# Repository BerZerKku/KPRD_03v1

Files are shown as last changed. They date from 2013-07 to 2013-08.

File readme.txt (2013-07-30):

КПРД v3.1

Клеммник комманд передатчика 16-и командный.
В отличии от предыдущих убрана возможность выбора напряжения работы.
Заменены оптроны на более защищенные.
Изменена цепь проверки, для работы с односторонним оптроном.
Входные сопротивления посажены на полигоны, с целью предотвратить их 
выпадания при нагреве.

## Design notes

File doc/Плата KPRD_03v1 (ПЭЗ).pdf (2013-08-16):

Поз.

### обозначе ние

Наименоенвие | Кол. | Примечание
Изм | Лист | № докум. | Подп. | Дата
Разраб. | Щеблыкин М.В | | 16-08-13 | Плата КПРД 03v1 Перечень элементов | Лит. | Лист | Листов
Провер. | Вершинин А.С. | | | | | 1 | 11

ООО
«Прософт-Системы»
Н.контр. | Назаренко А.Н
Утв. | Чирков А.Г.
AV1..AV16 | Оптрон ACPL-M50L-xxxx AVAGO | 16 | хх – любые символы
| (FODM453R2(V) FAIRCHILD, PS8101-AX(xx) CEL)

Конденсаторы

C1 | Чип 1206 X7R 100В 0.1мкФ ±10% | 1
C2 | Чип 1206 Y5V 50В 1мкФ ±20% | 1
C3 | Чип 1210 X7R(X5R, X7S) 50В 10мкФ ±10%(20) | 1
C4 | Чип 0805 X7R 50В 0.1мкФ ±10% | 1
C5 | Чип 1206 X7R 100В 0.1мкФ ±10% | 1
C6 | Чип 0805 X7R 50В 2200пФ ±10% | 1
C7 | Чип 0805 X7R 50В 0.1мкФ ±10% | 1
C8 | Чип 1206 X7R 100В 0.1мкФ ±10% | 1
C9 | Чип 0805 X7R 50В 2200пФ ±10% | 1
C10 | Чип 0805 X7R 50В 0.1мкФ ±10% | 1
C11 | Чип 1206 X7R 100В 0.1мкФ ±10% | 1
C12 | Чип 0805 X7R 50В 2200пФ ±10% | 1
C13 | Чип 0805 X7R 50В 0.1мкФ ±10% | 1
C14 | Чип 1206 X7R 100В 0.1мкФ ±10% | 1
C15 | Чип 0805 X7R 50В 2200пФ ±10% | 1
C16 | Чип 0805 X7R 50В 0.1мкФ ±10% | 1
C17 | Чип 1206 X7R 100В 0.1мкФ ±10% | 1
C18 | Чип 0805 X7R 50В 2200пФ ±10% | 1
C19 | Чип 0805 X7R 50В 0.1мкФ ±10% | 1
C20 | Чип 1206 X7R 100В 0.1мкФ ±10% | 1
C21 | Чип 0805 X7R 50В 2200пФ ±10% | 1
| | | ПБКМ.42 6439.004 ПЭ3

## ПБКМ.42 6439.005 ПЭ3

Лист

2 Изм | Лист | № докум. | Подп. | Дата
C22 | Чип 0805 X7R 50В 0.1мкФ ±10% | 1
C23 | Чип 1206 X7R 100В 0.1мкФ ±10% | 1
C24 | Чип 0805 X7R 50В 2200пФ ±10% | 1
C25 | Чип 0805 X7R 50В 0.1мкФ ±10% | 1
C26 | Чип 1206 X7R 100В 0.1мкФ ±10% | 1
C27 | Чип 0805 X7R 50В 2200пФ ±10% | 1
C28 | Чип 0805 X7R 50В 0.1мкФ ±10% | 1
C29 | Чип 1206 X7R 100В 0.1мкФ ±10% | 1
C30 | Чип 0805 X7R 50В 2200пФ ±10% | 1
C31 | Чип 0805 X7R 50В 0.1мкФ ±10% | 1
C32 | Чип 1206 X7R 100В 0.1мкФ ±10% | 1
C33 | Чип 0805 X7R 50В 2200пФ ±10% | 1
C34 | Чип 0805 X7R 50В 0.1мкФ ±10% | 1
C35 | Чип 1206 X7R 100В 0.1мкФ ±10% | 1
C36 | Чип 0805 X7R 50В 2200пФ ±10% | 1
C37 | Чип 0805 X7R 50В 0.1мкФ ±10% | 1
C38 | Чип 1206 X7R 100В 0.1мкФ ±10% | 1
C39 | Чип 0805 X7R 50В 2200пФ ±10% | 1
C40 | Чип 0805 X7R 50В 0.1мкФ ±10% | 1
C41 | Чип 1206 X7R 100В 0.1мкФ ±10% | 1
C42 | Чип 0805 X7R 50В 2200пФ ±10% | 1
C43 | Чип 0805 X7R 50В 0.1мкФ ±10% | 1
C44 | Чип 1206 X7R 100В 0.1мкФ ±10% | 1
C45 | Чип 0805 X7R 50В 2200пФ ±10% | 1
C46 | Чип 0805 X7R 50В 0.1мкФ ±10% | 1
C47 | Чип 1206 X7R 100В 0.1мкФ ±10% | 1
C48 | Чип 0805 X7R 50В 2200пФ ±10% | 1
C49 | Чип 0805 X7R 50В 0.1мкФ ±10% | 1
C50 | Чип 1206 X7R 100В 0.1мкФ ±10% | 1
C51 | Чип 0805 X7R 50В 2200пФ ±10% | 1

Лист | № докум. | Подп. | Дата

Резисторы

R1..R3 | Чип 2010 1кОм ±5% | 3
R4 | Чип 1206 2кОм ±5% | 1
R5 | SQM500JB-5K1 5.1кОм 5Вт ±5% YAGEO | 1
R6 | Чип 2010 1кОм ±5% | 1
R7 | Чип 1206 2кОм ±5% | 1
R8 | Чип 2010 1.2кОм ±5% | 1
R9 | Чип 2010 100Ом ±5% | 1
R10,R11 | SQM500JB-5K1 5.1кОм 5Вт ±5% YAGEO | 2
R12 | Чип 2010 1кОм ±5% | 1
R13 | Чип 1206 2кОм ±5% | 1
R14 | Чип 2010 1.2кОм ±5% | 1
R15 | Чип 2010 100Ом ±5% | 1
R16,R17 | SQM500JB-5K1 5.1кОм 5Вт ±5% YAGEO | 2
R18 | Чип 1206 2кОм ±5% | 1
R19 | Чип 2010 1кОм ±5% | 1
R20 | Чип 2010 1.2кОм ±5% | 1
R21 | Чип 2010 100Ом ±5% | 1
R22,R23 | SQM500JB-5K1 5.1кОм 5Вт ±5% YAGEO | 2
R24 | Чип 1206 2кОм ±5% | 1
R25 | Чип 2010 1кОм ±5% | 1
R26 | Чип 2010 1.2кОм ±5% | 1
R27 | Чип 2010 100Ом ±5% | 1
R28,R29 | SQM500JB-5K1 5.1кОм 5Вт ±5% YAGEO | 2
R30 | Чип 1206 2кОм ±5% | 1
R31 | Чип 2010 1кОм ±5% | 1
R32 | Чип 2010 1.2кОм ±5% | 1
R33 | Чип 2010 100Ом ±5% | 1
R34,R35 | SQM500JB-5K1 5.1кОм 5Вт ±5% YAGEO | 2
R36 | Чип 1206 2кОм ±5% | 1
R37 | Чип 2010 1кОм ±5% | 1
| | | 3 Изм

Лист | № докум. | Подп. | Дата
R38 | Чип 2010 1.2кОм ±5% | 1
R39 | Чип 2010 100Ом ±5% | 1
R40,R41 | SQM500JB-5K1 5.1кОм 5Вт ±5% YAGEO | 2
R42 | Чип 1206 2кОм ±5% | 1
R43 | Чип 2010 1кОм ±5% | 1
R44 | Чип 2010 1.2кОм ±5% | 1
R45 | Чип 2010 100Ом ±5% | 1
R46,R47 | SQM500JB-5K1 5.1кОм 5Вт ±5% YAGEO | 2
R48 | Чип 1206 2кОм ±5% | 1
R49 | Чип 2010 1кОм ±5% | 1
R50 | Чип 2010 1.2кОм ±5% | 1
R51 | Чип 2010 100Ом ±5% | 1
R52,R53 | SQM500JB-5K1 5.1кОм 5Вт ±5% YAGEO | 2
R54 | Чип 1206 2кОм ±5% | 1
R55 | Чип 2010 1кОм ±5% | 1
R56 | Чип 2010 1.2кОм ±5% | 1
R57 | Чип 2010 100Ом ±5% | 1
R58,R59 | SQM500JB-5K1 5.1кОм 5Вт ±5% YAGEO | 2
R60 | Чип 1206 2кОм ±5% | 1
R61 | Чип 2010 1кОм ±5% | 1
R62 | Чип 2010 1.2кОм ±5% | 1
R63 | Чип 2010 100Ом ±5% | 1
R64,R65 | SQM500JB-5K1 5.1кОм 5Вт ±5% YAGEO | 2
R66 | Чип 1206 2кОм ±5% | 1
R67 | Чип 2010 1кОм ±5% | 1
R68 | Чип 2010 1.2кОм ±5% | 1
R69 | Чип 2010 100Ом ±5% | 1
R70,R71 | SQM500JB-5K1 5.1кОм 5Вт ±5% YAGEO | 2
R72 | Чип 1206 2кОм ±5% | 1
R73 | Чип 2010 1кОм ±5% | 1
R74 | Чип 2010 1.2кОм ±5% | 1
R75 | Чип 2010 100Ом ±5% | 1
| | | 4 Изм

Лист | № докум. | Подп. | Дата
R76,R77 | SQM500JB-5K1 5.1кОм 5Вт ±5% YAGEO | 2
R78 | Чип 1206 2кОм ±5% | 1
R79 | Чип 2010 1кОм ±5% | 1
R80 | Чип 2010 1.2кОм ±5% | 1
R81 | Чип 2010 100Ом ±5% | 1
R82,R83 | SQM500JB-5K1 5.1кОм 5Вт ±5% YAGEO | 2
R84 | Чип 1206 2кОм ±5% | 1
R85 | Чип 2010 1кОм ±5% | 1
R86 | Чип 2010 1.2кОм ±5% | 1
R87 | Чип 2010 100Ом ±5% | 1
R88,R89 | SQM500JB-5K1 5.1кОм 5Вт ±5% YAGEO | 2
R90 | Чип 1206 2кОм ±5% | 1
R91 | Чип 2010 1кОм ±5% | 1
R92 | Чип 2010 1.2кОм ±5% | 1
R93 | Чип 2010 100Ом ±5% | 1
R94,R95 | SQM500JB-5K1 5.1кОм 5Вт ±5% YAGEO | 2
R96 | Чип 1206 2кОм ±5% | 1
R97 | Чип 2010 1кОм ±5% | 1
R98 | Чип 2010 1.2кОм ±5% | 1
R99 | Чип 2010 100Ом ±5% | 1
R100 | SQM500JB-5K1 5.1кОм 5Вт ±5% YAGEO | 1 | Вариант установки ГОСТ 29137-91 200.00.0000.00.00
TV1..TV16 | Трансформатор 78253/55MVC MURATA | 16

Диоды

VD1 | Супрессор P6SMB30СА 30В TSC | 1 | двунаправленный
| (P6SMB30CA LITTLEFUSE, P6SMB30CA VISHAY)
VD2 | BAT54C NXP | 1 | общий коллектор
| (VISHAY, FAIRCHILD и др.)
VD3 | Супрессор P6SMB47СА 47В TSC | 1 | двунаправленный
| (P6SMB47CA LITTLEFUSE, P6SMB47CA VISHAY)
| | | | 5 Изм

Лист | № докум. | Подп. | Дата
VD4 | STPS160A ST | 1
VD5 | Супрессор P6SMB6.8СА 6.8В TSC | 1 | двунаправленный
| (P6SMB6.8CA LITTLEFUSE, P6SMB6.8CA VISHAY)
VD6 | Супрессор P6SMB18А 18В TSC | 1 | однонаправленный
| (P6SMB18A LITTLEFUSE, P6SMB18A VISHAY)
VD7 | Супрессор 1.5SMC300CA 300В LITTLEFUSE | 1 | двунаправленный
| (1.5SMC300CA VISHAY)
VD8 | 1N4148WS FAIRCHILD | 1
| (1N4148WS-V VISHAY)
VD9 | BAT54C NXP | 1 | общий коллектор
| (VISHAY, FAIRCHILD и др.)
VD10 | Супрессор P6SMB6.8СА 6.8В TSC | 1 | двунаправленный
| (P6SMB6.8CA LITTLEFUSE, P6SMB6.8CA VISHAY)
VD11 | Супрессор P6SMB18А 18В TSC | 1 | однонаправленный
| (P6SMB18A LITTLEFUSE, P6SMB18A VISHAY)
VD12 | Супрессор 1.5SMC300CA 300В LITTLEFUSE | 1 | двунаправленный
| (1.5SMC300CA VISHAY)
VD13 | 1N4148WS FAIRCHILD | 1
| (1N4148WS-V VISHAY)
VD14 | BAT54C NXP | 1 | общий коллектор
| (VISHAY, FAIRCHILD и др.)
VD15 | Супрессор P6SMB6.8СА 6.8В TSC | 1 | двунаправленный
| (P6SMB6.8CA LITTLEFUSE, P6SMB6.8CA VISHAY)
VD16 | Супрессор P6SMB18А 18В TSC | 1 | однонаправленный
| (P6SMB18A LITTLEFUSE, P6SMB18A VISHAY)
VD17 | 1N4148WS FAIRCHILD | 1
| (1N4148WS-V VISHAY)
VD18 | Супрессор 1.5SMC300CA 300В LITTLEFUSE | 1 | двунаправленный
| (1.5SMC300CA VISHAY)
VD19 | BAT54C NXP | 1 | общий коллектор
| (VISHAY, FAIRCHILD и др.)
VD20 | Супрессор P6SMB6.8СА 6.8В TSC | 1 | двунаправленный
| | | | 6 Изм

Лист | № докум. | Подп. | Дата
| (P6SMB6.8CA LITTLEFUSE, P6SMB6.8CA VISHAY)
VD21 | Супрессор P6SMB18А 18В TSC | 1 | однонаправленный
| (P6SMB18A LITTLEFUSE, P6SMB18A VISHAY)
VD22 | 1N4148WS FAIRCHILD | 1
| (1N4148WS-V VISHAY)
VD23 | Супрессор 1.5SMC300CA 300В LITTLEFUSE | 1 | двунаправленный
| (1.5SMC300CA VISHAY)
VD24 | BAT54C NXP | 1 | общий коллектор
| (VISHAY, FAIRCHILD и др.)
VD25 | Супрессор P6SMB6.8СА 6.8В TSC | 1 | двунаправленный
| (P6SMB6.8CA LITTLEFUSE, P6SMB6.8CA VISHAY)
VD26 | Супрессор P6SMB18А 18В TSC | 1 | однонаправленный
| (P6SMB18A LITTLEFUSE, P6SMB18A VISHAY)
VD27 | 1N4148WS FAIRCHILD | 1
| (1N4148WS-V VISHAY)
VD28 | Супрессор 1.5SMC300CA 300В LITTLEFUSE | 1 | двунаправленный
| (1.5SMC300CA VISHAY)
VD29 | BAT54C NXP | 1 | общий коллектор
| (VISHAY, FAIRCHILD и др.)
VD30 | Супрессор P6SMB6.8СА 6.8В TSC | 1 | двунаправленный
| (P6SMB6.8CA LITTLEFUSE, P6SMB6.8CA VISHAY)
VD31 | Супрессор P6SMB18А 18В TSC | 1 | однонаправленный
| (P6SMB18A LITTLEFUSE, P6SMB18A VISHAY)
VD32 | 1N4148WS FAIRCHILD | 1
| (1N4148WS-V VISHAY)
VD33 | Супрессор 1.5SMC300CA 300В LITTLEFUSE | 1 | двунаправленный
| (1.5SMC300CA VISHAY)
VD34 | BAT54C NXP | 1 | общий коллектор
| (VISHAY, FAIRCHILD и др.)
VD35 | Супрессор P6SMB6.8СА 6.8В TSC | 1 | двунаправленный
| (P6SMB6.8CA LITTLEFUSE, P6SMB6.8CA VISHAY)
VD36 | Супрессор P6SMB18А 18В TSC | 1 | однонаправленный
| | | | 7 Изм

Лист | № докум. | Подп. | Дата
| (P6SMB18A LITTLEFUSE, P6SMB18A VISHAY)
VD37 | 1N4148WS FAIRCHILD | 1
| (1N4148WS-V VISHAY)
VD38 | Супрессор 1.5SMC300CA 300В LITTLEFUSE | 1 | двунаправленный
| (1.5SMC300CA VISHAY)
VD39 | BAT54C NXP | 1 | общий коллектор
| (VISHAY, FAIRCHILD и др.)
VD40 | Супрессор P6SMB6.8СА 6.8В TSC | 1 | двунаправленный
| (P6SMB6.8CA LITTLEFUSE, P6SMB6.8CA VISHAY)
VD41 | Супрессор P6SMB18А 18В TSC | 1 | однонаправленный
| (P6SMB18A LITTLEFUSE, P6SMB18A VISHAY)
VD42 | 1N4148WS FAIRCHILD | 1
| (1N4148WS-V VISHAY)
VD43 | Супрессор 1.5SMC300CA 300В LITTLEFUSE | 1 | двунаправленный
| (1.5SMC300CA VISHAY)
VD44 | BAT54C NXP | 1 | общий коллектор
| (VISHAY, FAIRCHILD и др.)
VD45 | Супрессор P6SMB6.8СА 6.8В TSC | 1 | двунаправленный
| (P6SMB6.8CA LITTLEFUSE, P6SMB6.8CA VISHAY)
VD46 | Супрессор P6SMB18А 18В TSC | 1 | однонаправленный
| (P6SMB18A LITTLEFUSE, P6SMB18A VISHAY)
VD47 | 1N4148WS FAIRCHILD | 1
| (1N4148WS-V VISHAY)
VD48 | Супрессор 1.5SMC300CA 300В LITTLEFUSE | 1 | двунаправленный
| (1.5SMC300CA VISHAY)
VD49 | BAT54C NXP | 1 | общий коллектор
| (VISHAY, FAIRCHILD и др.)
VD50 | Супрессор P6SMB6.8СА 6.8В TSC | 1 | двунаправленный
| (P6SMB6.8CA LITTLEFUSE, P6SMB6.8CA VISHAY)
VD51 | Супрессор P6SMB18А 18В TSC | 1 | однонаправленный
| (P6SMB18A LITTLEFUSE, P6SMB18A VISHAY)
VD52 | 1N4148WS FAIRCHILD | 1
| | | | 8 Изм

Лист | № докум. | Подп. | Дата
| (1N4148WS-V VISHAY)
VD53 | Супрессор 1.5SMC300CA 300В LITTLEFUSE | 1 | двунаправленный
| (1.5SMC300CA VISHAY)
VD54 | BAT54C NXP | 1 | общий коллектор
| (VISHAY, FAIRCHILD и др.)
VD55 | Супрессор P6SMB6.8СА 6.8В TSC | 1 | двунаправленный
| (P6SMB6.8CA LITTLEFUSE, P6SMB6.8CA VISHAY)
VD56 | Супрессор P6SMB18А 18В TSC | 1 | однонаправленный
| (P6SMB18A LITTLEFUSE, P6SMB18A VISHAY)
VD57 | 1N4148WS FAIRCHILD | 1
| (1N4148WS-V VISHAY)
VD58 | Супрессор 1.5SMC300CA 300В LITTLEFUSE | 1 | двунаправленный
| (1.5SMC300CA VISHAY)
VD59 | BAT54C NXP | 1 | общий коллектор
| (VISHAY, FAIRCHILD и др.)
VD60 | Супрессор P6SMB6.8СА 6.8В TSC | 1 | двунаправленный
| (P6SMB6.8CA LITTLEFUSE, P6SMB6.8CA VISHAY)
VD61 | Супрессор P6SMB18А 18В TSC | 1 | однонаправленный
| (P6SMB18A LITTLEFUSE, P6SMB18A VISHAY)
VD62 | 1N4148WS FAIRCHILD | 1
| (1N4148WS-V VISHAY)
VD63 | Супрессор 1.5SMC300CA 300В LITTLEFUSE | 1 | двунаправленный
| (1.5SMC300CA VISHAY)
VD64 | BAT54C NXP | 1 | общий коллектор
| (VISHAY, FAIRCHILD и др.)
VD65 | Супрессор P6SMB6.8СА 6.8В TSC | 1 | двунаправленный
| (P6SMB6.8CA LITTLEFUSE, P6SMB6.8CA VISHAY)
VD66 | Супрессор P6SMB18А 18В TSC | 1 | однонаправленный
| (P6SMB18A LITTLEFUSE, P6SMB18A VISHAY)
VD67 | 1N4148WS FAIRCHILD | 1
| (1N4148WS-V VISHAY)
VD68 | Супрессор 1.5SMC300CA 300В LITTLEFUSE | 1 | двунаправленный
| | | | 9 Изм

Лист | № докум. | Подп. | Дата
| (1.5SMC300CA VISHAY)
VD69 | BAT54C NXP | 1 | общий коллектор
| (VISHAY, FAIRCHILD и др.)
VD70 | Супрессор P6SMB6.8СА 6.8В TSC | 1 | двунаправленный
| (P6SMB6.8CA LITTLEFUSE, P6SMB6.8CA VISHAY)
VD71 | Супрессор P6SMB18А 18В TSC | 1 | однонаправленный
| (P6SMB18A LITTLEFUSE, P6SMB18A VISHAY)
VD72 | 1N4148WS FAIRCHILD | 1
| (1N4148WS-V VISHAY)
VD73 | Супрессор 1.5SMC300CA 300В LITTLEFUSE | 1 | двунаправленный
| (1.5SMC300CA VISHAY)
VD74 | BAT54C NXP | 1 | общий коллектор
| (VISHAY, FAIRCHILD и др.)
VD75 | Супрессор P6SMB6.8СА 6.8В TSC | 1 | двунаправленный
| (P6SMB6.8CA LITTLEFUSE, P6SMB6.8CA VISHAY)
VD76 | Супрессор P6SMB18А 18В TSC | 1 | однонаправленный
| (P6SMB18A LITTLEFUSE, P6SMB18A VISHAY)
VD77 | 1N4148WS FAIRCHILD | 1
| (1N4148WS-V VISHAY)
VD78 | Супрессор 1.5SMC300CA 300В LITTLEFUSE | 1 | двунаправленный
| (1.5SMC300CA VISHAY)
VD79 | BAT54C NXP | 1 | общий коллектор
| (VISHAY, FAIRCHILD и др.)
VD80 | Супрессор P6SMB6.8СА 6.8В TSC | 1 | двунаправленный
| (P6SMB6.8CA LITTLEFUSE, P6SMB6.8CA VISHAY)
VD81 | Супрессор P6SMB18А 18В TSC | 1 | однонаправленный
| (P6SMB18A LITTLEFUSE, P6SMB18A VISHAY)
VD82 | 1N4148WS FAIRCHILD | 1
| (1N4148WS-V VISHAY)
VD83 | Супрессор 1.5SMC300CA 300В LITTLEFUSE | 1 | двунаправленный
| (1.5SMC300CA VISHAY)
VD84 | BAT54C NXP | 1 | общий коллектор
| | | | 10 Изм

| | | | 11 Изм
Лист | № докум. | Подп. | Дата

(VISHAY, FAIRCHILD и др.)

VT1 | Транзистор BCV72 NXP | 1
| (FAIRCHILD)

Разъемы

X1 | DIN 41612 3*32 96 MR | 1 | вилка угловая
X2 | 231-576/001-000 WAGO | 1 | 16 контактов, угловой
X3 | 231-576/001-000 WAGO | 1 | 16 контактов, угловой
X4 | PLS-2 | 1 | 2.54мм

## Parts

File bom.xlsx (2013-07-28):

Item Number | Description | Case | Quantity | Part Reference | Comment
7 | Диод 1N4148WS FAIRCHILD (1N4148WS-V VISHAY) | SOD-323 | 16 | VD8,VD13,VD17,VD22,VD27,VD32,VD37,VD42,VD47,VD52,VD57,VD62,VD67,VD72,VD77,VD82
9 | Диод BAT54C NXP (VISHAY, FAIRCHILD и др.) | SOT-23_3 | 17 | VD2,VD9,VD14,VD19,VD24,VD29,VD34,VD39,VD44,VD49,VD54,VD59,VD64,VD69,VD74,VD79,VD84 | общий коллектор
11 | Диод STPS160A ST | DO-214AC | 1 | VD4
13 | Супрессор P6SMB6.8СА 6.8В двунаправленный TSC (P6SMB6.8CA LITTLEFUSE, P6SMB6.8CA VISHAY) | DO-214AA | 16 | VD5,VD10,VD15,VD20,VD25,VD30,VD35,VD40,VD45,VD50,VD55,VD60,VD65,VD70,VD75,VD80
15 | Супрессор P6SMB18А 18В однонаправленный TSC (P6SMB18A LITTLEFUSE, P6SMB18A VISHAY) | DO-214AA | 16 | VD6,VD11,VD18,VD23,VD28,VD33,VD38,VD43,VD48,VD53,VD58,VD63,VD68,VD73,VD78,VD83
17 | Супрессор P6SMB30СА 30В двунаправленный TSC (P6SMB30CA LITTLEFUSE, P6SMB30CA VISHAY) | DO-214AA | 1 | VD1
19 | Супрессор P6SMB47СА 47В двунаправленный TSC (P6SMB47CA LITTLEFUSE, P6SMB47CA VISHAY) | DO-214AA | 1 | VD3
21 | Супрессор 1.5SMC300CA 300В двунаправленный LITTLEFUSE (1.5SMC300CA VISHAY) | DO-214AB | 16 | VD7,VD12,VD16,VD21,VD26,VD31,VD36,VD41,VD46,VD51,VD56,VD61,VD66,VD71,VD76,VD81
23
25 | Конденсатор - чип 0805 X7R 50В 2200пФ ±10% | 0805 | 16 | C6,C9,C12,C15,C18,C21,C24,C27,C30,C33,C36,C39,C42,C45,C48,C51
27 | Конденсатор - чип 1206 X7R 100В 0.1мкФ ±10% | 1206 | 17 | C1,C5,C8,C11,C14,C17,C20,C23,C26,C29,C32,C35,C38,C41,C44,C47,C50
29 | Конденсатор - чип 0805 X7R 50В 0.1мкФ ±10% | 0805 | 16 | C4,C7,C10,C13,C16,C19,C22,C25,C28,C31,C34,C37,C40,C43,C46,C49
31 | Конденсатор - чип 1206 Y5V 50В 1мкФ ±20% | 1206 | 1 | C2
33 | Конденсатор - чип 1210 X7R(X5R, X7S) 50В 10мкФ ±10%(20) | 1210 | 1 | C3
35
37 | Оптрон ACPL-M50L-xxxx AVAGO (FODM453R2(V) FAIRCHILD, PS8101-AX(xx) CEL) | SMT_6 | 16 | AV1-AV16
39
41 | Разъем 231-576/001-000 WAGO | 16 pins | 2 | X2,X3 | 16 контактов на плату
43 | Разъем DIN 41612 3*32 96 MR вилка угловая | 96 pins | 1 | X1 | угловой, вилка, ряды А,В и С по 32 контакта
45 | Разъем PLS-2 | 2 pins | 1 | X4 | 2.54мм
47
49 | Резистор - чип 2010 100Ом ±5% | 2010 | 16 | R9,R15,R21,R27,R33,R39,R45,R51,R57,R63,R69,R75,R81,R87,R93,R99
51 | Резистор - чип 2010 1кОм ±5% | 2010 | 18 | R1,R2,R6,R12,R18,R24,R30,R36,R42,R48,R54,R60,R66,R72,R78,R84,R90,R96
53 | Резистор - чип 1206 1кОм ±5% | 1206 | 1 | R3
55 | Резистор - чип 2010 1.2кОм ±5% | 2010 | 16 | R8,R14,R19,R25,R31,R37,R43,R49,R55,R61,R67,R73,R79,R85,R91,R97
57 | Резистор - чип 1206 2кОм ±5% | 1206 | 17 | R4,R7,R13,R20,R26,R32,R38,R44,R50,R56,R62,R68,R74,R80,R86,R92,R98
59 | Резистор SQM500JB-5K1 5.1кОм 5Вт ±5% | 2 pins | 32 | R5,R10,R11,R16,R17,R22,R23,R28,R29,R34,R35,R40,R41,R46,R47,R52,R53,R58,R59,R64,R65,R70,R71,R76,R77,R82,R83,R88,R89,R94,R95,R100 | Вариант установки ГОСТ 29137-91 200.00.0000.00.00
61
63 | Транзистор BCV72 NXP | SOT-23 | 1 | VT1
65
67 | Трансформатор 78253/55MVC MURATA | SM-6 | 16 | TV1-TV16

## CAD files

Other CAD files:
doc/Плата KPRD_03v1 (СБ).dwg

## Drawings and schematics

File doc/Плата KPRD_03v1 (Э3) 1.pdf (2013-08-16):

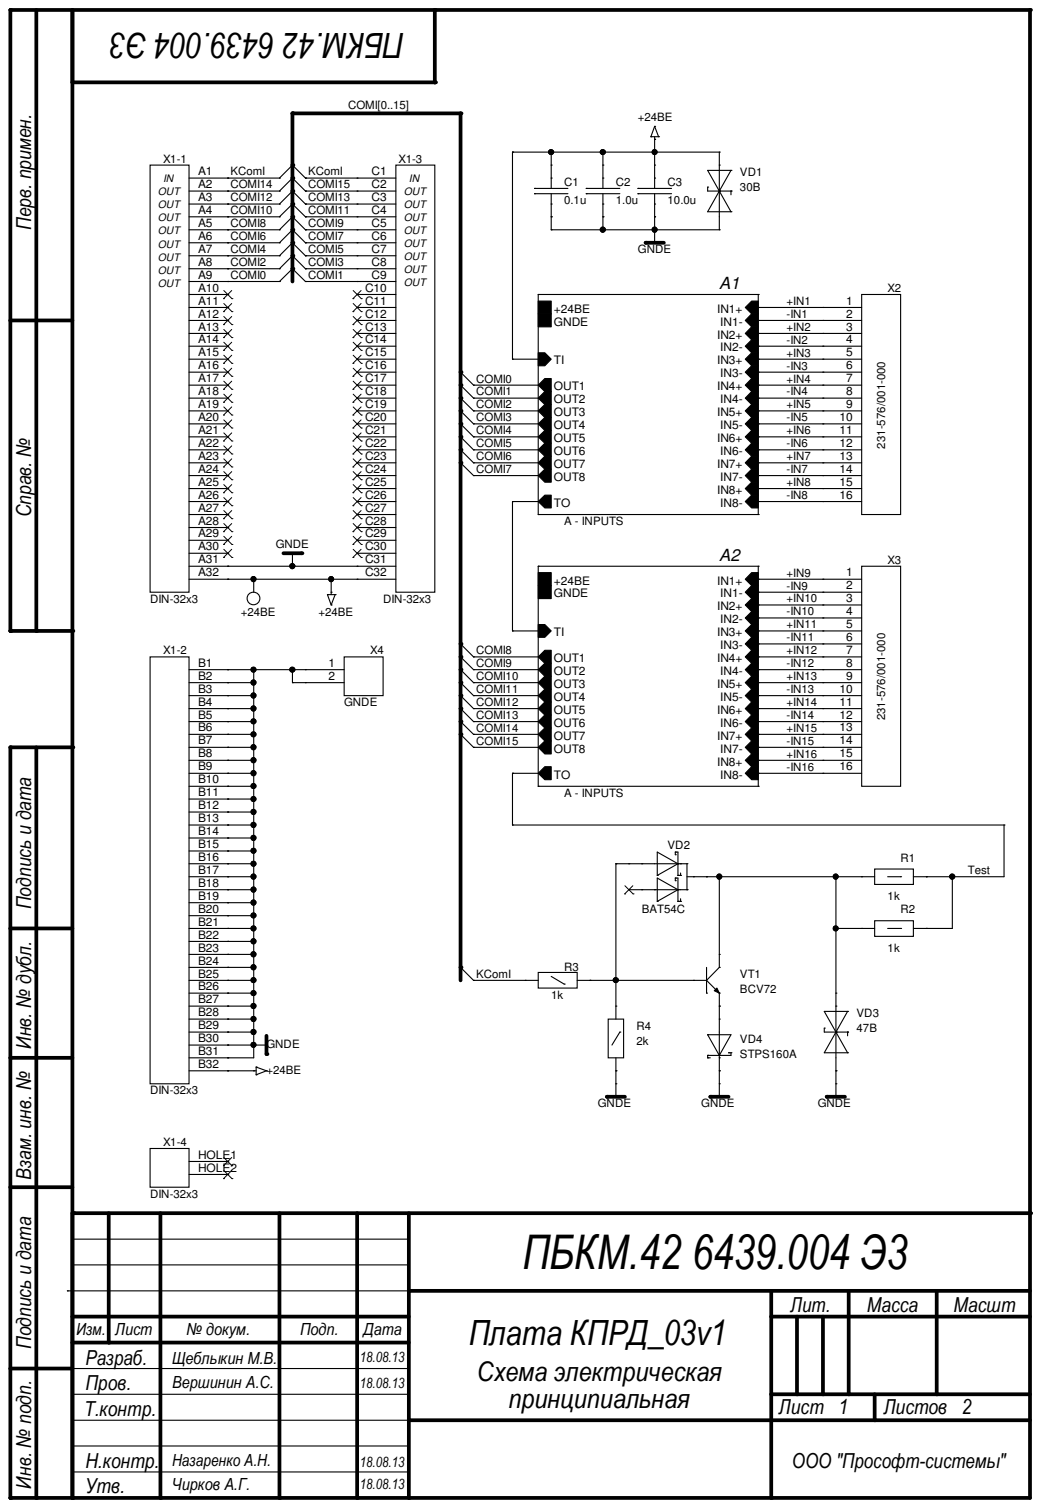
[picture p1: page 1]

Инв. № подп. Подпись и дата Взам. инв. № Инв. № дубл. П

ПБКМ.42 6439.004 Э3

Плата КПРД_03v1 Схема электрическая принципиальная | Лит. | Масса | Масшт

Изм. | Лист | № докум. | Подп. | Дата
Разраб. | | Щеблыкин М.В. | | 18.08.13
Пров. | Вершинин А.С. | | 18.08.13
Т.контр. | | | | | Лист 1 | Листов 2

Н.контр. | Назаренко А.Н. | 18.08.13
Утв. | Чирков А.Г. | 18.08.13

ООО "Прософт-системы"

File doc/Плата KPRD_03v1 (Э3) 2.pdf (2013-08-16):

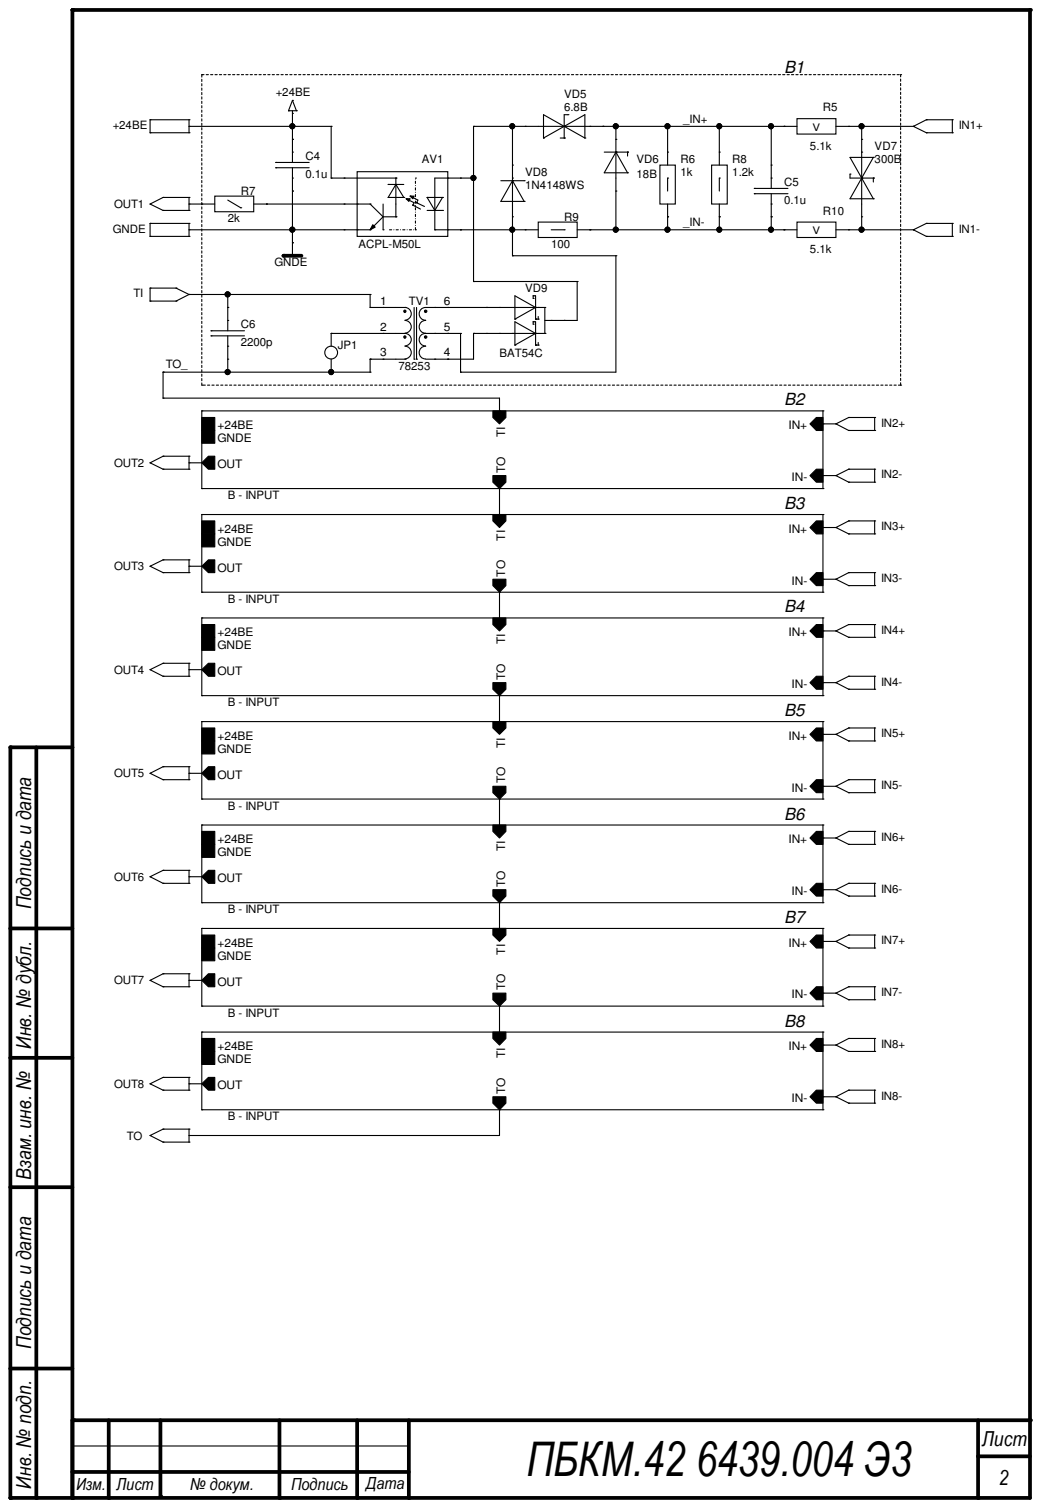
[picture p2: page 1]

Инв. № подп. Подпись и дата Взам. инв. № Инв. № дубл. Подпись и дата

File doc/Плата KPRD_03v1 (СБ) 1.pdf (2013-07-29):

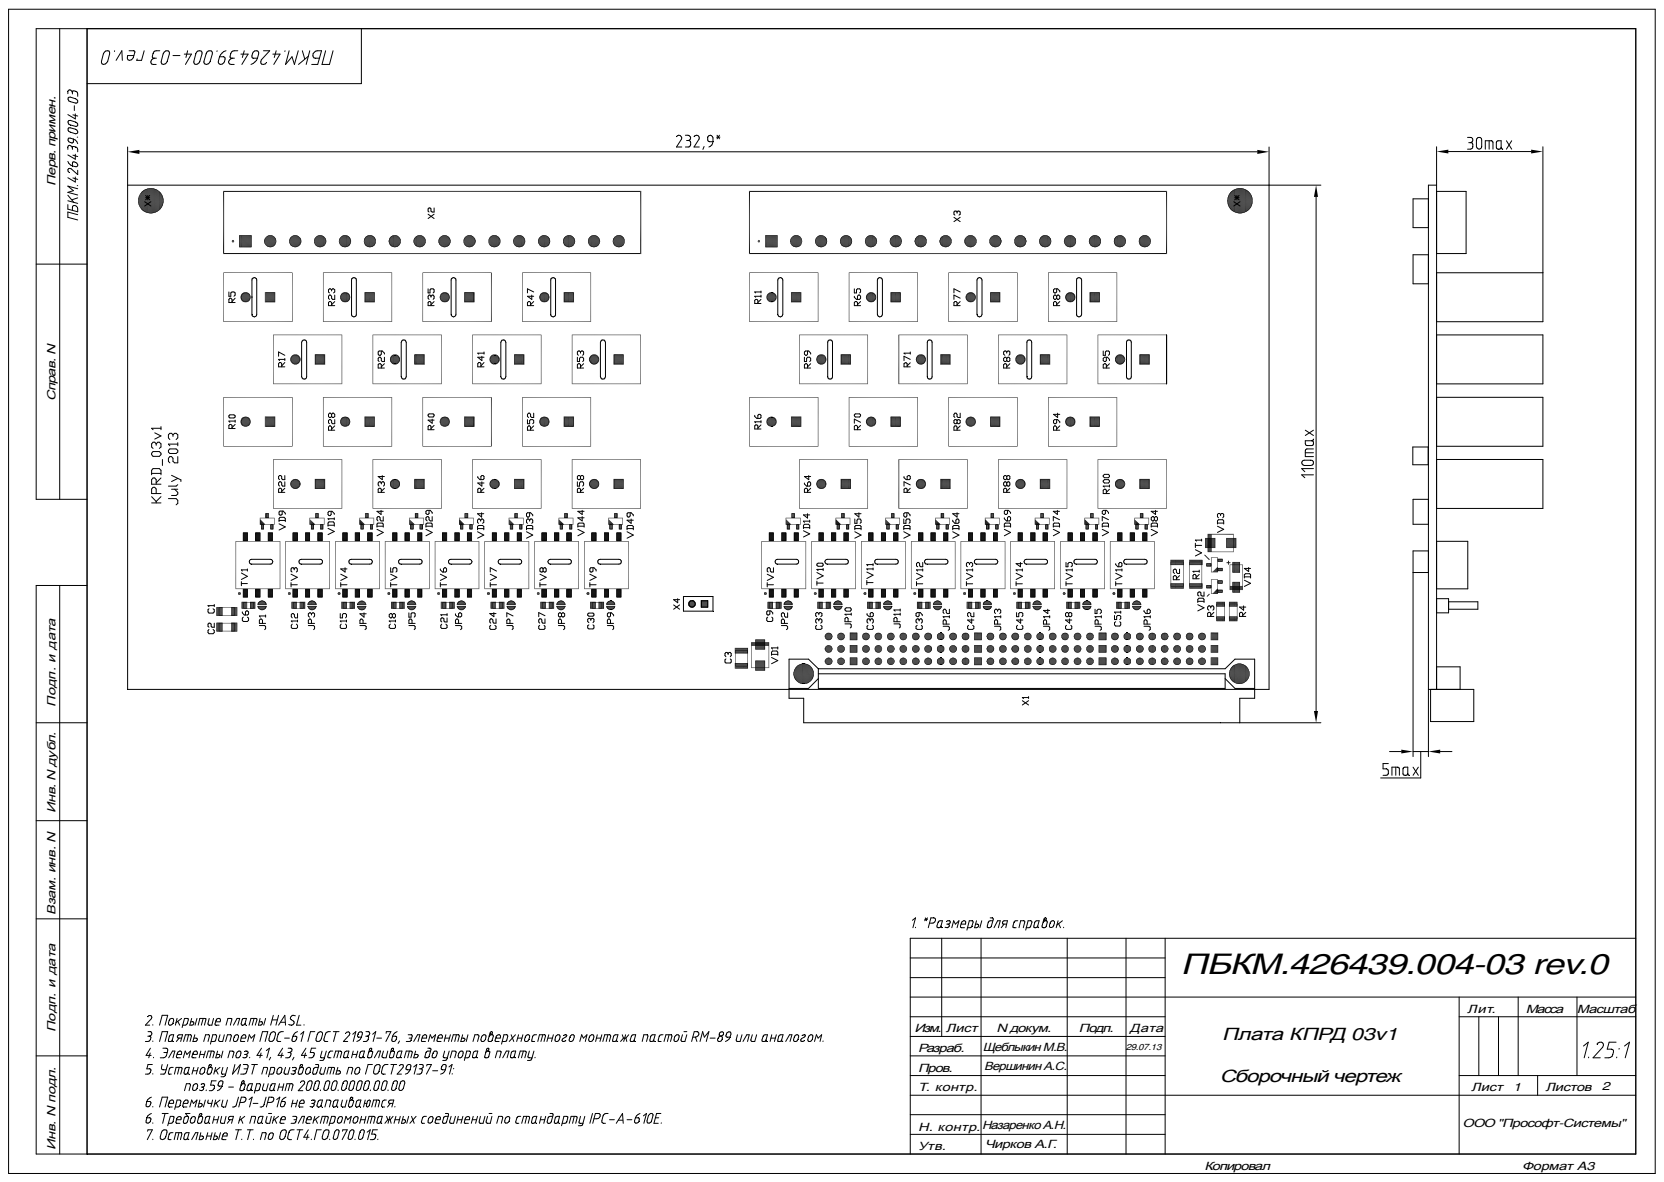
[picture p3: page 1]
Копировал; Формат A3

Перв. примен. Справ. N Подп. и дата Инв. N дубл. Взам. инв. N Подп. и дата Инв. N подл.

ПБКМ.426439.004-03 rev.0

Плата КПРД 03v1 Сборочный чертеж | Лит. | Масса | Масштаб

Изм. Лист | N докум. | Подп. | Дата
Разраб. | Щеблыкин М.В. | | 29.07.13
Пров. | Вершинин А.С.
Т. контр. | | | | Лист 1 | Листов 2

Н. контр. | Назаренко А.Н.
Утв. | Чирков А.Г.

ООО "Прософт-Системы"

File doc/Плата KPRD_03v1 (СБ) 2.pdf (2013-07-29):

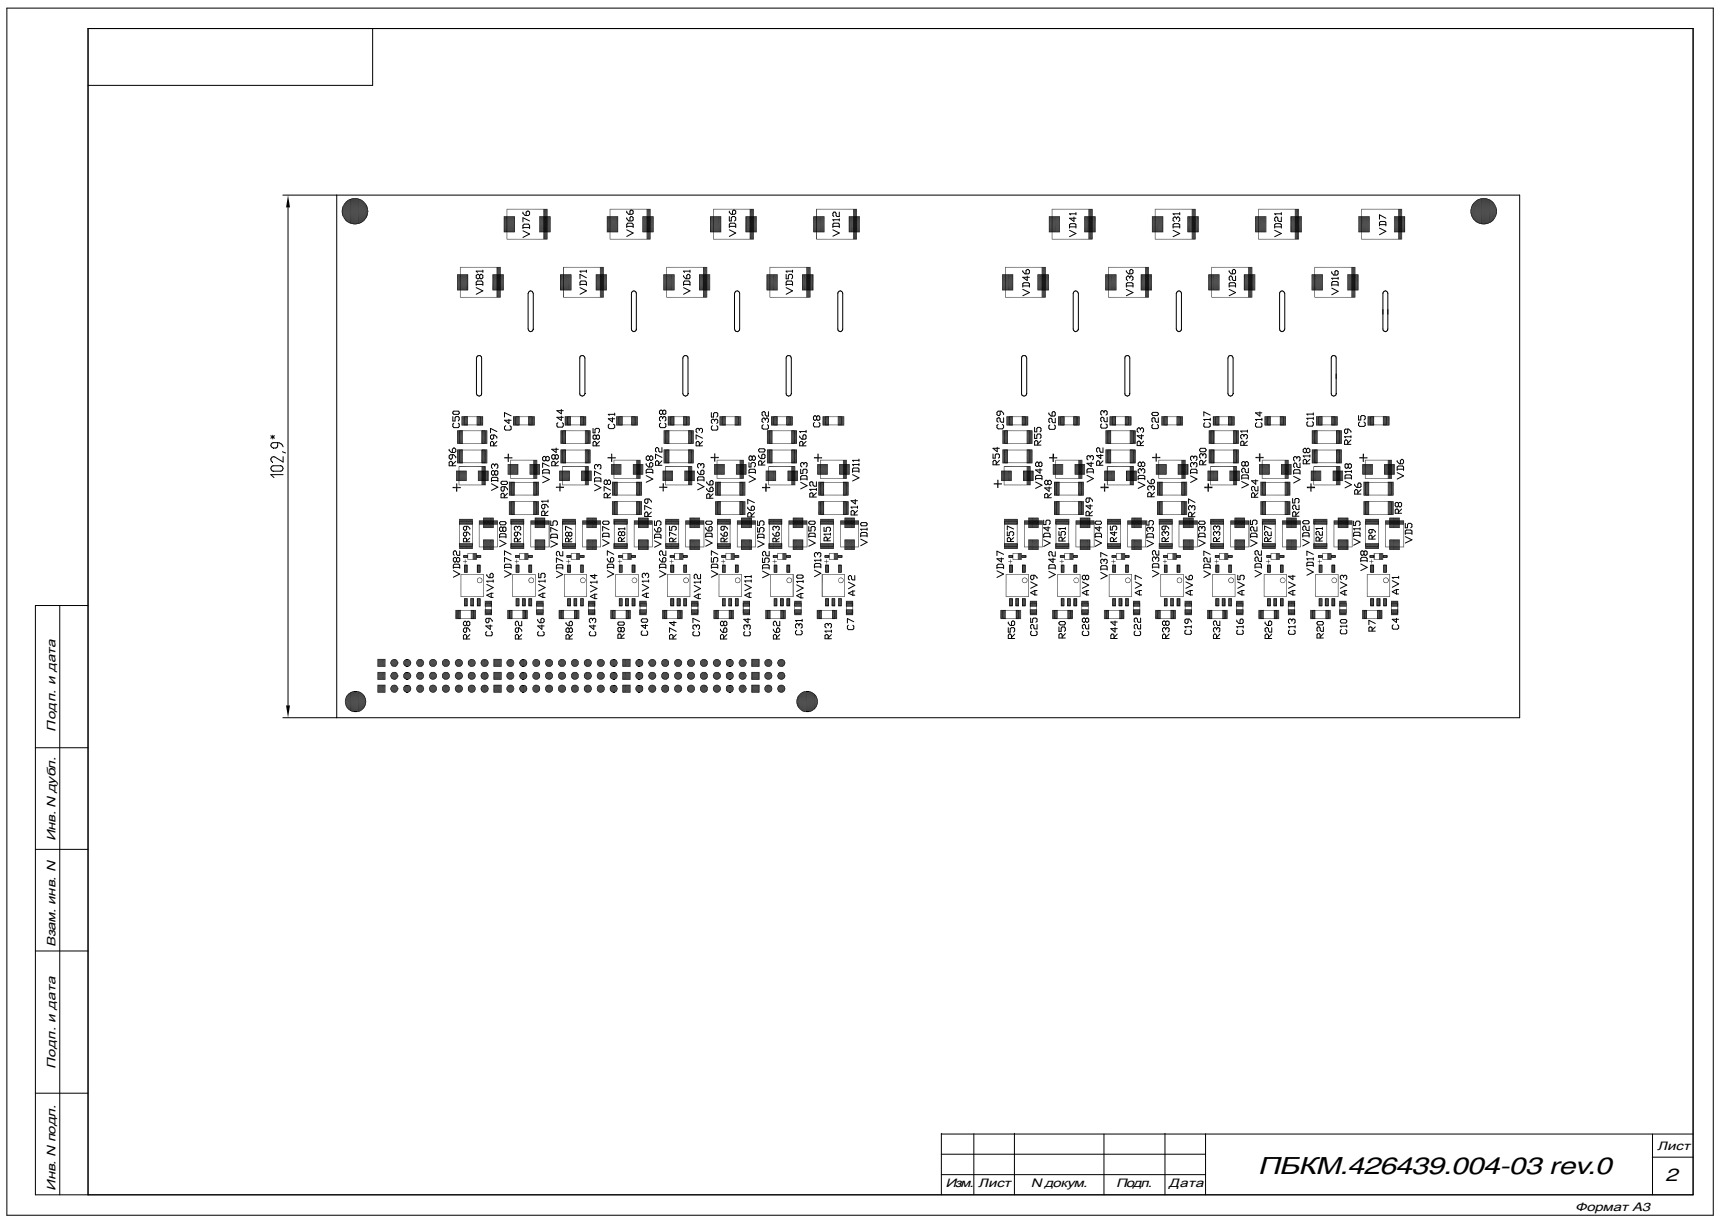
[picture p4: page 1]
Лист; Формат A3; Изм. Лист; N докум.; Подп.; Дата; ПБКМ.426439.004-03 rev.0

Подп. и дата Инв. N дубл. Взам. инв. N Подп. и дата Инв. N подл.

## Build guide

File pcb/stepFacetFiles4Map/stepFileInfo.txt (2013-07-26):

#STEP_FILE ! FILE_SIZE | MOD_TIME

LED 0603 Green.step ! 113239 ! 1372843388
DO-214AB.STEP ! 787405 ! 1372619486
Capacitor SMD FK-Type H13.step ! 139187 ! 1372843388
Capacitor 1206.STEP ! 598585 ! 1372843388
Inductor 1812.step ! 86760 ! 1372843388
Transformer 78253MVC_SMD.STEP ! 2693976 ! 1372843388
SOT23-3.step ! 148105 ! 1374733880
IC_SOIC20_W_AD.STEP ! 106995 ! 1372843388
FUSE LP30-110.step ! 765093 ! 1372843388
Resistor SQM5W.step ! 626261 ! 1374732572
SOD-323.step ! 93059 ! 1374734399
DC_DC_ SIP_7_4.step ! 2047842 ! 1372843388
Resistor 2010.STEP ! 204413 ! 1374671824
Capacitor 0805.STEP ! 934995 ! 1372843388
Resistor 1206.step ! 598323 ! 1372843388
DO-214AA.step ! 209060 ! 1372843388
IDC-10M.STEP ! 238925 ! 1372843388
SO-5 JEDEC MO-155.STEP ! 315946 ! 1372712518

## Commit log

2013-07-25 Плата KPRD_03v1 Вновь.
    [KPRD_03V1.DSN, kprd_03v1.brd]
2013-07-25 Добавлен файл игнора и файл для степ моделей.
2013-07-25 Начата расстановка SMD jumpers.
    [KPRD_03V1.DSN, kprd_03v1.brd]
2013-07-26 Сделаны входные цепи. Расстояния провод провод для входа 2мм, расстояние вход - цепь после резистора 1.3мм.
    [kprd_03v1.brd]
2013-07-26 Добавлены супрресоры по входам команд. Исправлена разводка.
    [KPRD_03V1.DSN, kprd_03v1.brd]
2013-07-26 Добавлены пазы под оптронами и переходные отверстия соединяющие полигоны земли.
    [KPRD_03V1.DSN, kprd_03v1.brd]
2013-07-28 На плату добавлены реперные точки, джампер для земли и КТ для напряжения.
    [KPRD_03V1.DSN, kprd_03v1.brd]
2013-07-28 Подготовлены слои сборки. Добавлены герберы и файл сверловки.
    [art_param.txt, kprd_03v1.brd, nc_param.txt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]
2013-07-28 Добавлены сгенерированный bom на плату и оформленная СП.
    [bom.xlsx]
2013-07-29 Немного поправлена разводка.
    [kprd_03v1.brd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]
2013-07-29 Добавлены герберы для масок.
    [nc_param.txt]
2013-07-29 Добавлено несколько масок в файл игнорирования.
2013-07-29 Немного изменена разводка. Сделан glossing.
    [kprd_03v1.brd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]
2013-07-29 Сделана документация. Отдана на проверку.
    [Плата КПРМ KPRD_03v1 (СБ).dwg]
2013-07-29 На плате исправлен слой bottom_assembly, были удалены полярности не у тех супрессоров. Документация прошла НК.
    [kprd_03v1.brd, Плата КПРМ KPRD_03v1 (СБ).dwg]
2013-07-30 СП rev.0 СБ rev.0
    Для разъема WAGO добавлен аналог. Они отличаются только размерами ножек.
2013-07-30 Добавлен файл описания.
2013-07-30 Исправлена маска на планарных джамперах, сформирован гербер.
2013-07-30 Исправлена маска и файл для просмотрщика.
2013-08-16 На схемы поставлены титулы по ГОСТ. Изменено название документации, стояло ошибочное "КПРМ".
    [KPRD_03V1.DSN, Плата KPRD_03v1 (СБ).dwg]
2013-08-16 Добавлен перечень элементов.
    [KPRD_03V1.DSN]
